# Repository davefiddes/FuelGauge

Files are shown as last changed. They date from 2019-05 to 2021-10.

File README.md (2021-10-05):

# Linear Fuel Gauge

This project allows an accurate linear fuel readout to be created for vehicles with unusually shaped fuel tanks and/or mismatched fuel senders.

## Why?

I built this for my Ultima GTR kit car which uses a conventional VDO fuel gauge and vertical float sender unit. The fuel tank on the car is a very unusual shape so it can get as much fuel as possible into a small space. This combination means that with a thirsty V8 the fuel quickly drops from 100% to 25% but takes a lot longer to go from 25% to empty. It's easy to run out of fuel!

To illustrate the scale of the problem here is a rendering of the fuel tank with 15 litres of fuel in a 34 litre tank:

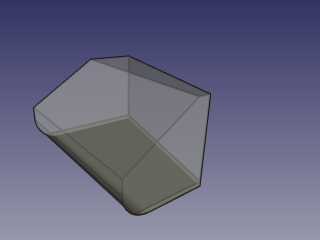
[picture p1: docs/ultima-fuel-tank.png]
Cutaway render of Ultima GTR fuel tank


Other Ultima owners have solved the problem by using their ECU or an intelligent dashboard. I have neither and wanted to preserve the original look of the Ultima branded instruments.

## How?

The Linear Fuel Gauge box sits between a standard resistance fuel sender and a hot-wire fuel gauge. The device:

* measures the resistance of the sender (0-100 ohms)
* maps that resistance to a linear fuel level value
* maps the fuel level to a particular gauge output value
* emulates the resistance value needed to achieve the required gauge output value

## Hardware

The gauge is built around a simple 8-pin PIC12F1840 micro-controller. The resistance of the sender is measured using a 10mA current source built from an LM317L regulator. The gauge output is achieved by feeding a PWM signal from the MCU into a high-current MOSFET driver (currents are typically around 100mA for 100%). A simple NPN-transistor driver is provided for low fuel indication. Configuration of the gauge is achieved with a 3-wire TTL serial connection to the MCU.

The project contains the full Kicad schematics and a PCB layout designed to fit in a small Hammond Manufacturing 1591ABK ABS plastic case.

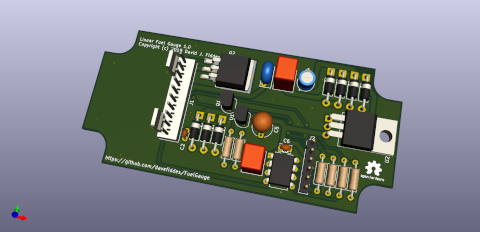
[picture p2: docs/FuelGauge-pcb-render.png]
Fuel Gauge PCB 3D render


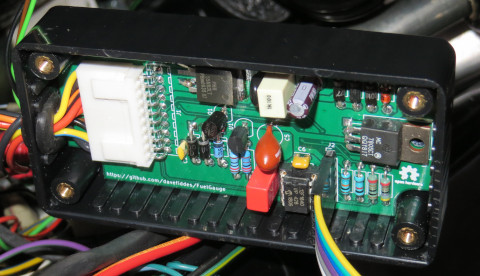
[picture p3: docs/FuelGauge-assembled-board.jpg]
Fuel Gauge assembled unit


Details:

* [Schematics](hardware/FuelGauge.pdf)
* [PCB Gerbers](hardware/gerbers/FuelGauge-1.0.zip)
* [BOM](docs/BOM.md)
* [Example Wiring Harness](wiring/wiring.pdf)

## Software



The gauge is implemented in C as a platform neutral core with a small hardware abstraction layer for the MCU. A full set of unit tests is provided for the core allowing easy testing and debugging to be carried out on a PC before building for the MCU. The MCU firmware is built using the Microchip MPLAB X IDE v5.15 and xc8 v2.05 compiler (Free Version).

 The gauge has two 9 bin maps that allow fine grained mapping of:

* the input resistance to a linear fuel level
* the linear fuel level to a PWM gauge output value

 The calibration of the two maps is achieved using a serial connection. The core implements a command processor allowing values in each of the maps to be modified and saved to EEPROM. During calibration the gauge output can be tested and the resistance of the fuel sender measured independently.

 The [Calibration And Programming Guide](docs/user-guide.md) details how to set up the fuel gauge which should mostly be a one-time exercise.

## License

 The device hardware and software is covered by the GNU General Public License v3.

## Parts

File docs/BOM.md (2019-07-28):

Fuel Gauge Bill of Materials
--------------------------------

Below is the Bill of Materials for the Fuel Gauge 1.0 board:

```
Ref(s)      Value                                   RS Components P/N
-------------------------------------------------------------------------------
C1,C2       1nF 100Vdc Multi-layer Ceramic 10%          699-5109
C3          1uF 100Vdc Polyester 10%                    126-2282
C4          22uF Aluminium Electrolytic 35Vdc           715-2729
C5          47uF 6.3V Radial Tantalum                   868-5690
C6          100nF 50Vdc Multi-layer Ceramic 10%         538-1310
D1,D2,D4,D6 1N4001                                      628-8931
D3          5V1 1W Zener Diode                          166-2747
D5          12V 1W Zener Diode                          687-5459
D7          22V 1.3W Zener Diode                        813-3915
J1          Molex KK 254 7395, 2.54mm Pitch, 10 Way     173-2994
            1 Row, Right Angle PCB Header
J2          6 Way 1 Row 2.54mm Pitch header
Q1          BC547 NPN Transistor TO-92                  671-1113
Q2          PHB55N03LT N-MOSFET transistor TO-263
R1          120R 1/4W 1% thin-film resistor
R2          2K2 1/4W 1% thin-film resistor
R3          1K 1/4W 1% thin-film resistor
R4          10R 1/4W 1% thin-film resistor
R5          4K7 1/4W 1% thin-film resistor
R6          10K 1/4W 1% thin-film resistor
RV1         Panasonic ERZV05D220 22V MOV                226-7817
U1          LM317L 100mA Linear regulator TO92          661-6796
U2          LM7805 700mA Linear Regulator TO220         785-6762
U3          Microchip PIC12F1840-I/P DIP-8              743-2697
```

Notes:
 * Q2 may be hard to find. Any power N-channel MOSFET in TO-263 package should suffice. I used a device recovered from a PC motherboard as that what I had available.

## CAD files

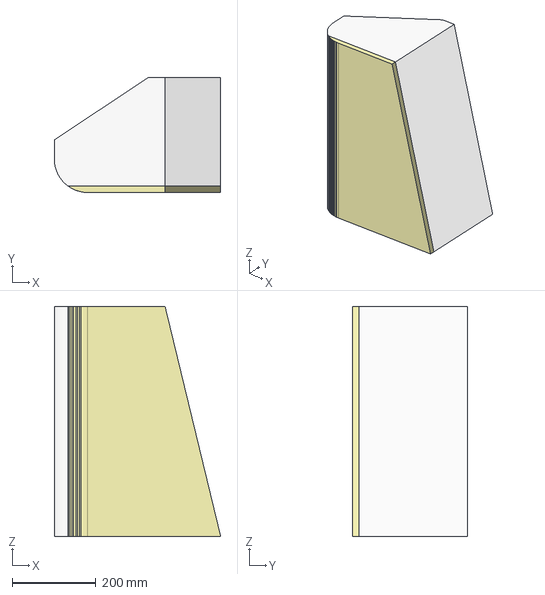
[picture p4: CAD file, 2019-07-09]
docs/ultima-fuel-tank.FCStd
398.0 x 275.0 x 550.0 mm
FuelTank
Fuel

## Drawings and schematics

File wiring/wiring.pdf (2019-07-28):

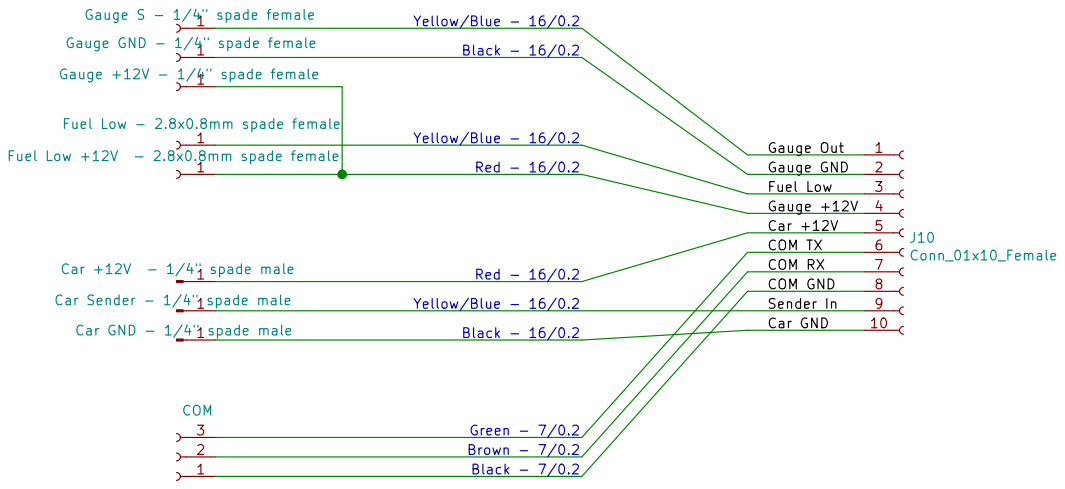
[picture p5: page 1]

Black - 16/0.2 Yellow/Blue - 16/0.2 Red - 16/0.2 Red - 16/0.2 Yellow/Blue - 16/0.2 Black - 16/0.2 Green - 7/0.2 Brown - 7/0.2 Black - 7/0.2

1 Gauge S - 1/4" spade female
1 Gauge GND - 1/4" spade female

1 Fuel Low - 2.8x0.8mm spade female

1 Fuel Low +12V - 2.8x0.8mm spade female

COM RX
Sender In COM GND

Car Sender - 1/4" spade male 1 Car GND - 1/4" spade male 1

File: wiring.sch Sheet: /
Id: 1/1 Title: Wiring Harness

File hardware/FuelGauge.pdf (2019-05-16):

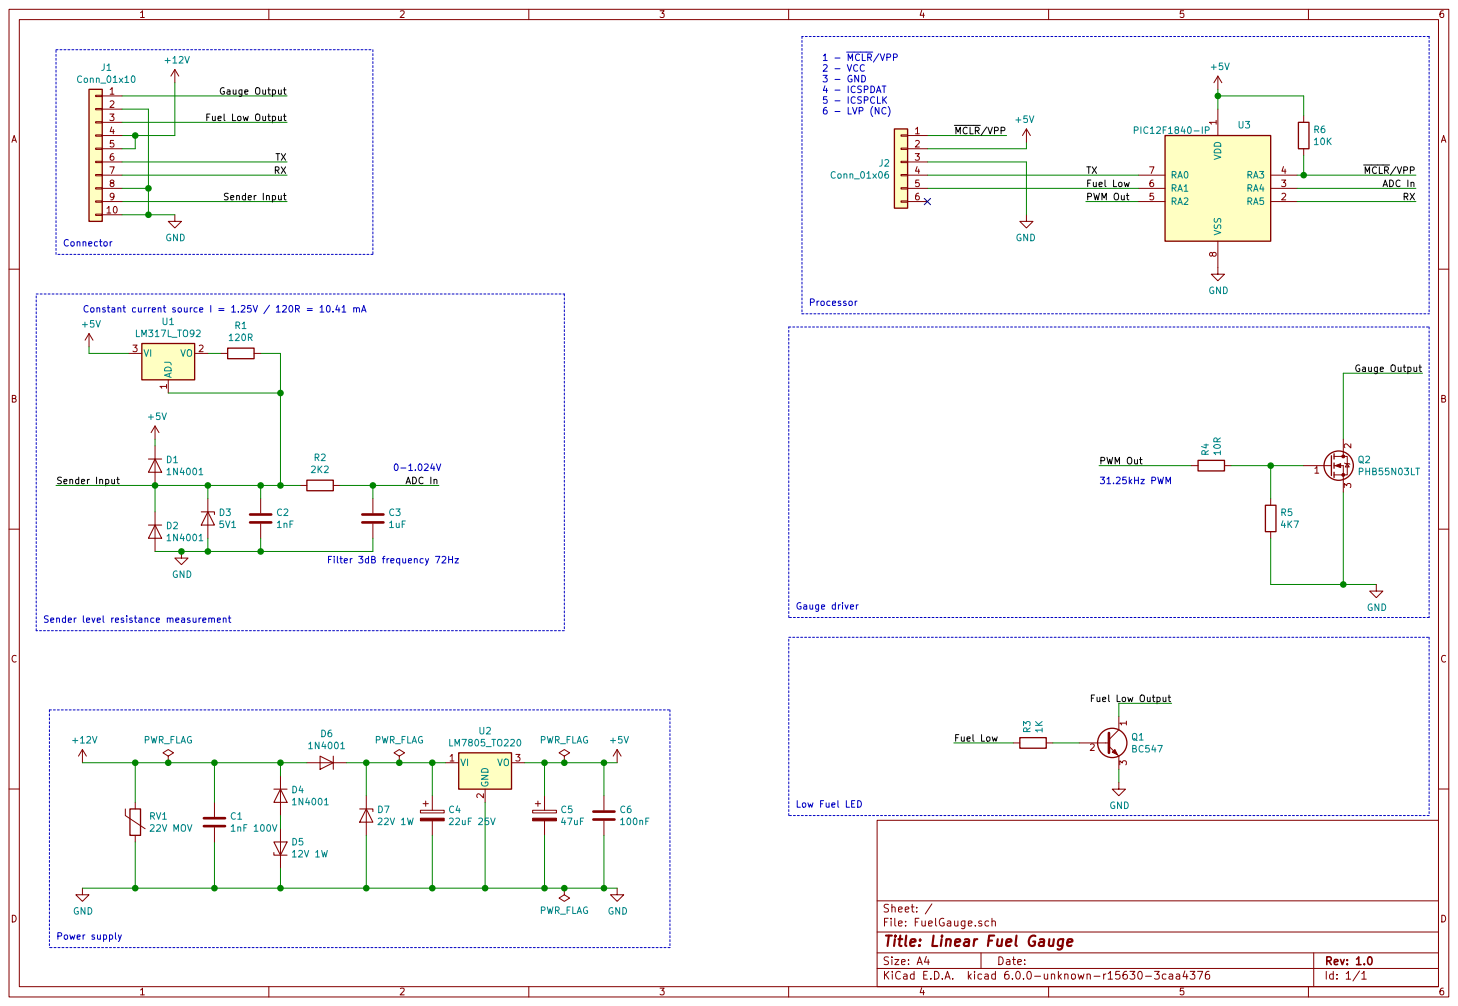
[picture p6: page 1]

+5V Constant current source I = 1.25V / 120R = 10.41 mA C2

File: FuelGauge.sch Sheet: / D6

Id: 1/1 Title: Linear Fuel Gauge

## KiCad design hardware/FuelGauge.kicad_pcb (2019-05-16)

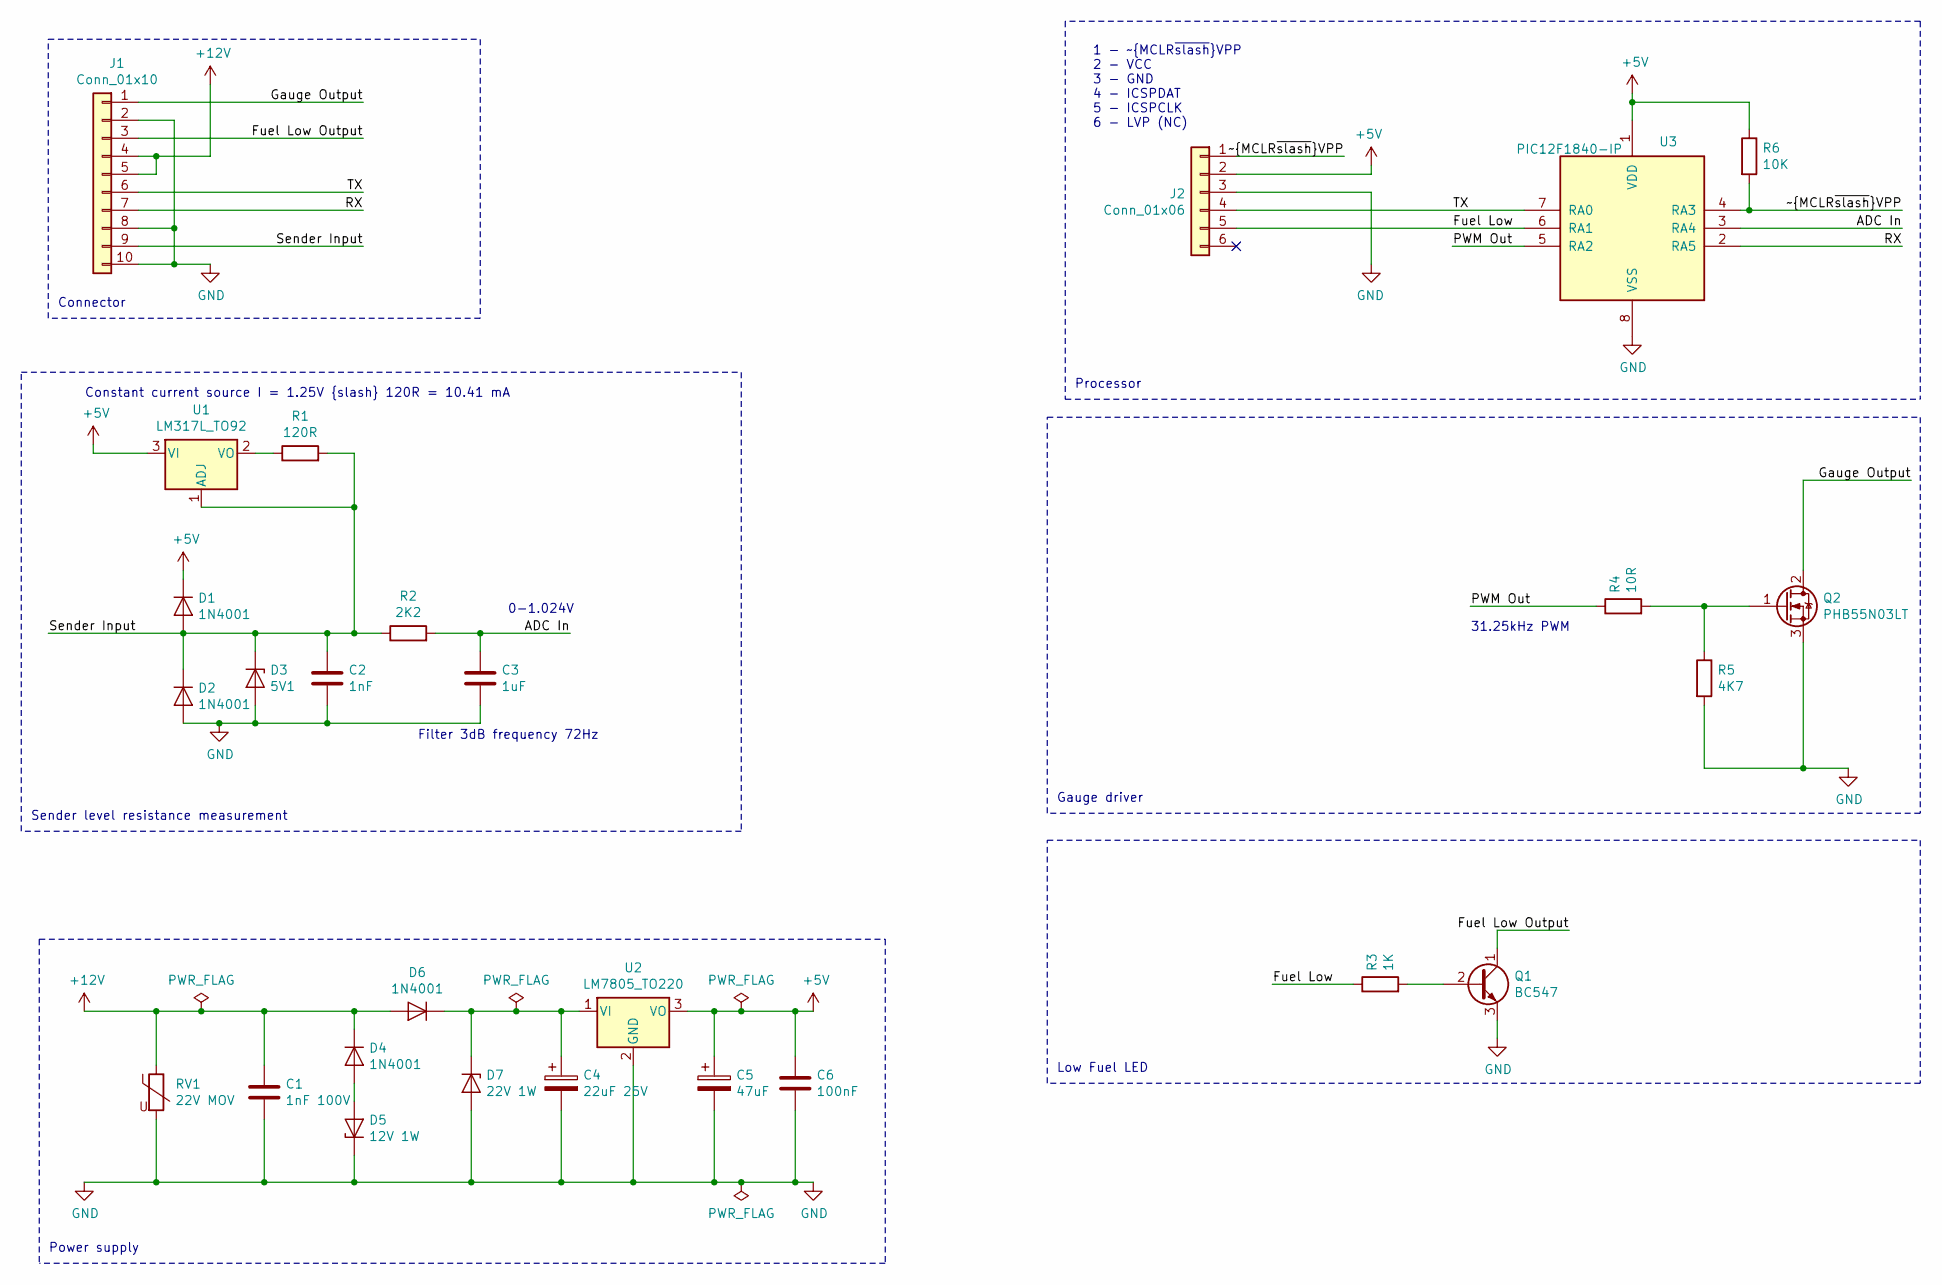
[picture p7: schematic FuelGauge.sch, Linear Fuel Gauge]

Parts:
C1: 1nF 100V; C_Rect_L7.0mm_W6.0mm_P5.00mm
C2: 1nF; C_Disc_D3.0mm_W1.6mm_P2.50mm
C3: 1uF; C_Rect_L7.0mm_W6.0mm_P5.00mm
C4: 22uF 25V; CP_Radial_D5.0mm_P2.00mm
C5: 47uF; CP_Radial_Tantal_D6.0mm_P5.00mm
C6: 100nF; C_Disc_D3.4mm_W2.1mm_P2.50mm
D1, D2, D4, D6: 1N4001; D_DO-41_SOD81_P10.16mm_Horizontal
D3: 5V1; D_DO-41_SOD81_P10.16mm_Horizontal
D5: 12V 1W; D_DO-41_SOD81_P10.16mm_Horizontal
D7: 22V 1W; D_DO-41_SOD81_P10.16mm_Horizontal
J1: Conn_01x10; Molex_KK-254_AE-6410-10A_1x10_P2.54mm_Vertical
J2: Conn_01x06; PinHeader_1x06_P2.54mm_Vertical
Q1: BC547; TO-92_Inline
Q2: PHB55N03LT; TO-263-3_TabPin2
R1: 120R; R_Axial_DIN0207_L6.3mm_D2.5mm_P10.16mm_Horizontal
R2: 2K2; R_Axial_DIN0207_L6.3mm_D2.5mm_P10.16mm_Horizontal
R3: 1K; R_Axial_DIN0207_L6.3mm_D2.5mm_P10.16mm_Horizontal
R4: 10R; R_Axial_DIN0207_L6.3mm_D2.5mm_P10.16mm_Horizontal
R5: 4K7; R_Axial_DIN0207_L6.3mm_D2.5mm_P10.16mm_Horizontal
R6: 10K; R_Axial_DIN0207_L6.3mm_D2.5mm_P10.16mm_Horizontal
RV1: 22V MOV; RV_Disc_D7mm_W3.4mm_P5mm
U1: LM317L_TO92; TO-92_Inline
U2: LM7805_TO220; TO-220-3_Horizontal_TabDown
U3: PIC12F1840-IP; DIP-8_W7.62mm

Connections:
+5V: C5.1, C6.1, D1.1 (K), J2.2, R6.1, U1.3 (VI), U2.3 (VO), U3.1 (VDD)
+12V: C1.1, D4.1 (K), D6.2 (A), J1.4, J1.5, RV1.1
/ADC In: C3.1, R2.2, U3.3 (RA4)
/Fuel Low: J2.5, R3.1, U3.6 (RA1)
/Fuel Low Output: J1.3, Q1.1 (C)
/Gauge Output: J1.1, Q2.2 (D)
/PWM Out: R4.1, U3.5 (RA2)
/RX: J1.7, U3.2 (RA5)
/Sender Input: C2.1, D1.2 (A), D2.1 (K), D3.1 (K), J1.9, R1.2, R2.1, U1.1 (ADJ)
/TX: J1.6, J2.4, U3.7 (RA0)
/~MCLR~/VPP: J2.1, R6.2, U3.4 (RA3)
GND: C1.2, C2.2, C3.2, C4.2, C5.2, C6.2, D2.2 (A), D3.2 (A), D5.1 (K), D7.2 (A), J1.2, J1.8, J1.10, J2.3, Q1.3 (E), Q2.3 (S), R5.2, RV1.2, U2.2 (GND), U3.8 (VSS)
unnamed: C4.1, D6.1 (K), D7.1 (K), U2.1 (VI)
unnamed: D4.2 (A), D5.2 (A)
unnamed: Q1.2 (B), R3.2
unnamed: Q2.1 (G), R4.2, R5.1
unnamed: R1.1, U1.2 (VO)

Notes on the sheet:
Constant current source I = 1.25V {slash} 120R = 10.41 mA
Filter 3dB frequency 72Hz
0-1.024V
31.25kHz PWM
Connector
Sender level resistance measurement
Processor
Gauge driver
Low Fuel LED
Power supply
1 - ~MCLR~{slash}VPP 2 - VCC 3 - GND 4 - ICSPDAT 5 - ICSPCLK 6 - LVP (NC)

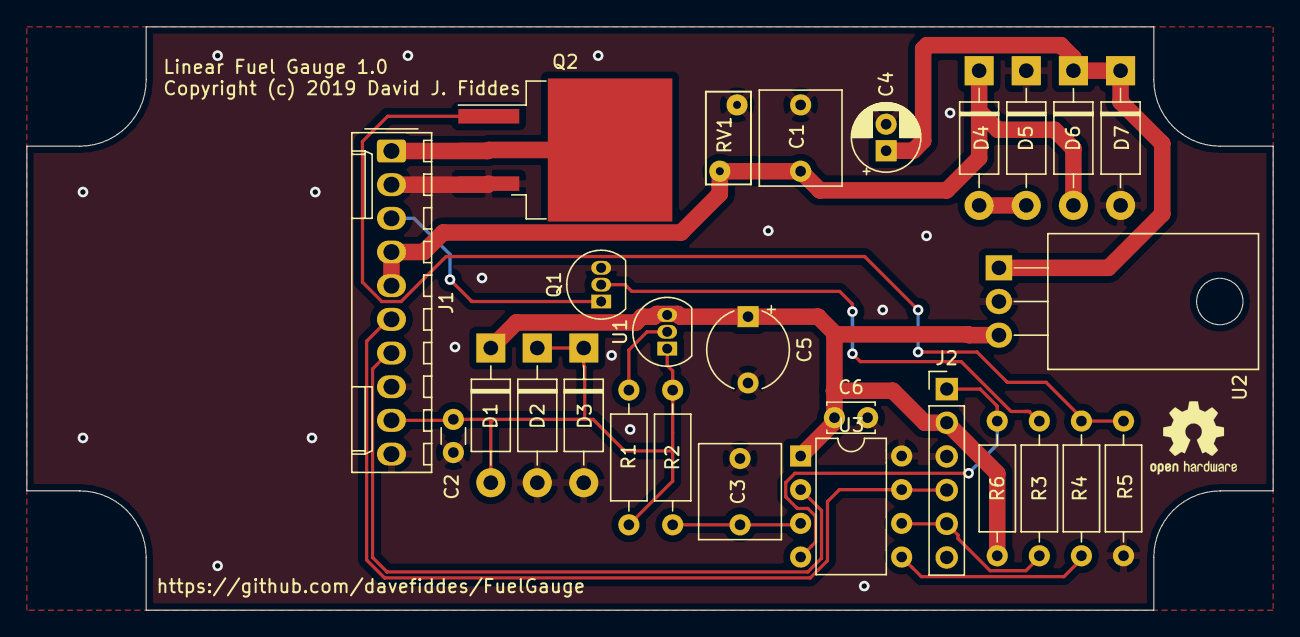
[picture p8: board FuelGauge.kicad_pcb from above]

Board: 2 copper layers, 94.0 x 44.0 mm, 28 parts (0 on the bottom side), 17 nets.

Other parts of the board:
Logo1: OSHW-Logo2_7.3x6mm_SilkScreen

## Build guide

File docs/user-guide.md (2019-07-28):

# Calibration And Programming Guide

## Connection

Connect to the Fuel Gauge using a 5V TTL capable USB serial device. Any common device should work whether based on FTDI, CP210x or CH340 chipsets. Use 9600 baud 8 bits and no-parity. TTL serial works surprisingly well even in a noisy vehicle environment and it saves the expense of an RS232 serial transceiver for a function that is rarely used.

## Usage

The fuel gauge offers a simple text based programming interface. The commands supported can be obtained by pressing `u` and then Enter:

```
FuelGauge Version a6408e

Press "u" for usage

u
Usage:
p               - Program mode
r               - Run mode
d               - Display current tank input value and output gauge value
g <Value>       - Output raw gauge value
t               - One shot test map the current tank input to the gauge output
i <Bin> <Value> - Set the input bin number to a specific linear tank value
o <Bin> <Value> - Set the output bin number to a specific value
m               - Display the input and output maps
s               - Save input and output maps to persistent storage
l               - Load input and output maps from persistent storage
f <Value>       - Set the low fuel limit
c               - Continuously output values as the gauge runs
u               - This usage information

OK
```

## Command Details

 * `p` - Changes from the normal running of the gauge to program mode. In this mode the sender input is no longer mapped to the output. This allows the gauge output to be manually altered. In particular this allows the output map to be created.

 * `r` - Restores the gauge to normal running operation

 * `d` - Display the raw values being read from the sender input, being output to the gauge and whether the device is in program or run mode. For example: `Tank: 0x1dbc Gauge: 0xffc0 Mode: Run`

 * `g` - Only available in program mode. This sets the gauge output to the specified 4-digit hex value. Useful for verifying what value is required for a given fuel gauge display.

 * `t` - Available in program mode this allows a one-shot test of mapping the current sender input through to the gauge output. This is handy for testing a map in response to a change in the sender input.

 * `i` - Used to configure a specific input map bin. The input map consists of 9 bins numbered 0 to 8. Each bin maps a given raw sender input value to a fixed _real_ fuel level value. For example bin 0 corresponds to empty, 4 to 50% full and 8 is 100% full.

 * `o` - Used to configure a specific output map bin. The output map consists of 9 bins numbered 0 to 8. In contrast to the input map the output map takes a _real_ fuel value and determines the raw gauge output value that is required.

 * `m` - Used to display the input and output maps and the configured low fuel light level

 * `s` - Save the current configuration to EEPROM. If this is not done it will be lost at the next power cycle.

 * `l` - Load the current configuration from EEPROM. This can be used if an error has been made during programming.

 * `f` - Set the fuel level which will cause the low fuel level warning lamp to illuminate. The value is in _real_ linear fuel level values. So 8000 means 50%, 2000 means 12.5% and so on.

 * `c` - Continuous mode will continuously log the sender input, actual fuel level and gauge output to the serial console several times a second. This allows rapid changes in the values to be quantified. This only available in run mode and when the sender input is not disconnected (a sender value of 0xffff).

 ## Calibration Procedure

 __**WARNING: Calibrating fuel gauges will likely involve moving measuring quantities of fuel around a vehicle. Please ensure appropriate ventilation, safety equipment and fire extinguishers. **__

 The first step is to calibrate the gauge output. Put the gauge into program mode and use the `g` command to set various values. The device is capable of generating a PWM output from 0% to 100% duty cycle. It is likely that the 0% gauge level will require a modest current on most hot-wire gauges. Note the gauge output values that achieve a given reading on the actual fuel gauge. Use these to program the output map. The map should work well for gauges which are divided into 1/8ths but may require a spreadsheet to figure out the values for a different graduations (e.g. 1/10ths).

 The next step is to determine the fuel tank calibration. To do this requires an empty fuel tank. Measure the empty fuel level using the `d` command and then store this in bin 0 of the input map using the `i` command. Add 1/8th of a tank of fuel using a calibrated measure and repeat until full.

 Finally set the low fuel warning level and save the map. Using a logging terminal like PuTTY and printing out a copy of the map with `m` will allow the maps to be restored in the case of an error.

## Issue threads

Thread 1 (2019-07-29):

It is difficult to remove the device from a vehicle

davefiddes, 2019-07-29:
I find it difficult to remove the device from a vehicle. It is possible to unplug the wiring harness from the PCB but only after unplugging from the 8 fiddling individual connections into my car's wiring loom. This makes it harder to remove the device for programming or testing as by necessity the wiring harness is short to allow it to be hidden under the dashboard.

A better choice might have been to use a DB-9 connector in place of the 10-pin 0.1" Molex header. This would allow external disconnection of the wiring harness from the device in a single operation. This would be similar to the DB-37 used by the MegaSquirt ECU.

It might be possible to wire a chassis mount DB-9 to the PCB but a PCB mount DB-9 connector would be neater.

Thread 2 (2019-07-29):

PCB footprint for U1 and Q1 is difficult to solder

davefiddes, 2019-07-29:
The choice of PCB footprint for the two TO-92 devices makes it difficult to solder manually. A more traditional footprint with offset middle pin and larger pads would be preferable as well as offering greater mechanical support for the devices.

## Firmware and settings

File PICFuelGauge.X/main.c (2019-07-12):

///////////////////////////////////////////////////////////////////////////////
//!
//! \file
//! \brief  Fuel Gauge main
//!
///////////////////////////////////////////////////////////////////////////////
// Copyright (c) 2019 David J. Fiddes
//
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
///////////////////////////////////////////////////////////////////////////////

#include "mcc_generated_files/mcc.h"
#include <command.h>
#include <ctype.h>
#include <hal.h>

//
//! Length of our input line buffer
//
#define BUFFERLEN 20

//
//! The number of loop iterations we need to flash at approx 1Hz
//
#define ERRORFLASHDURATION 1000

///////////////////////////////////////////////////////////////////////////////
//!
//! \brief  Device main loop
//!
///////////////////////////////////////////////////////////////////////////////
void main( void )
{
    // initialise the device
    SYSTEM_Initialize();

    // When using interrupts, you need to set the Global and Peripheral
    // Interrupt Enable bits Use the following macros to:

    // Enable the Global Interrupts
    // INTERRUPT_GlobalInterruptEnable();

    // Enable the Peripheral Interrupts
    // INTERRUPT_PeripheralInterruptEnable();

    // Disable the Global Interrupts
    // INTERRUPT_GlobalInterruptDisable();

    // Disable the Peripheral Interrupts
    // INTERRUPT_PeripheralInterruptDisable();

//
// Quote a version string to turn it into a C-string
//
#define VERSION_STR( x ) VERSION_STR1( x )
#define VERSION_STR1( x ) #x

    HAL_PrintText( "FuelGauge Version " VERSION_STR(
        GIT_VERSION ) "\r\n\r\nPress \"u\" for usage\r\n\r\n" );

    //
    // Check to see if we have experienced a watchdog reset.
    // Note: This needs the -mresetbits compiler option set otherwise this
    // information is clobbered by the normal start up code
    //
    if ( __timeout == 0 )
    {
        HAL_PrintText( "Watchdog timeout\r\n\r\n" );
    }

    //
    // Start the PWM output
    //
    TMR2_StartTimer();

    InitialiseGauge();

    char        rxData;
    char        lineBuffer[ BUFFERLEN ];
    const char* lineBufferBegin = &lineBuffer[ 0 ];
    const char* lineBufferEnd = lineBufferBegin + BUFFERLEN;
    char*       bufferPos = (char*)lineBufferBegin;
    int         errorCount = 0;

    *bufferPos = '\0';

    while ( 1 )
    {
        //
        // Check to see if we have a character waiting
        //
        if ( EUSART_is_rx_ready() )
        {
            rxData = EUSART_Read();

            if ( rxData == '\r' )
            {
                //
                // Echo the CR before doing any work
                //
                HAL_PrintNewline();

                *bufferPos = '\0';

                //
                // Process our line buffer as a new command
                //
                if ( ProcessCommand( lineBuffer ) )
                {
                    HAL_PrintText( "OK" );
                    HAL_PrintNewline();
                }
                else
                {
                    HAL_PrintText( "Command Error" );
                    HAL_PrintNewline();
                }
                bufferPos = (char*)lineBufferBegin;
                *bufferPos = '\0';
            }
            else if ( isprint( rxData ) )
            {
                //
                // Local echo
                //
                if ( EUSART_is_tx_ready() )
                {
                    EUSART_Write( rxData );
                }

                //
                // Store the character in our line buffer and check for length
                //
                *bufferPos = rxData;
                bufferPos++;
                if ( bufferPos == lineBufferEnd )
                {
                    HAL_PrintNewline();
                    HAL_PrintText( "Line too long" );
                    HAL_PrintNewline();
                    bufferPos = (char*)lineBufferBegin;
                    *bufferPos = '\0';
                }
            }
        }

        //
        // Run the gauge main loop
        //
        if ( !RunGauge() )
        {
            //
            // If we don't already have an error flash in progress start a
            // new one
            //
            if ( errorCount == 0 )
            {
                //
                // The error flash will have a 50% duty cycle so double the
                // interations
                //
                errorCount = ERRORFLASHDURATION * 2;
                lowFuel_SetHigh();
            }
        }

        //
        // If we have an outstanding error take care of flashing the low fuel
        // LED
        //
        if ( errorCount > 0 )
        {
            if ( errorCount == ERRORFLASHDURATION )
            {
                lowFuel_SetLow();
            }
            errorCount--;

            //
            // Wait for 1ms which should be enough to keep the main loop
            // responsive but not require huge numbers of iterations to build
            // longer delays for the error flash
            //
            __delay_ms( 1 );
        }

        //
        // Strobe the watchdog every time round the main loop so we don't reboot
        //
        CLRWDT();
    }
}

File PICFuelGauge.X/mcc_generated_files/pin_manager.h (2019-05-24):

/**
  @Generated Pin Manager Header File

  @Company:
    Microchip Technology Inc.

  @File Name:
    pin_manager.h

  @Summary:
    This is the Pin Manager file generated using PIC10 / PIC12 / PIC16 / PIC18 MCUs

  @Description
    This header file provides APIs for driver for .
    Generation Information :
        Product Revision  :  PIC10 / PIC12 / PIC16 / PIC18 MCUs - 1.76
        Device            :  PIC12F1840
        Driver Version    :  2.11
    The generated drivers are tested against the following:
        Compiler          :  XC8 2.00
        MPLAB 	          :  MPLAB X 5.10	
*/

/*
    (c) 2018 Microchip Technology Inc. and its subsidiaries. 
    
    Subject to your compliance with these terms, you may use Microchip software and any 
    derivatives exclusively with Microchip products. It is your responsibility to comply with third party 
    license terms applicable to your use of third party software (including open source software) that 
    may accompany Microchip software.
    
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
    IN NO EVENT WILL MICROCHIP BE LIABLE FOR ANY INDIRECT, SPECIAL, PUNITIVE, 
    INCIDENTAL OR CONSEQUENTIAL LOSS, DAMAGE, COST OR EXPENSE OF ANY KIND 
    WHATSOEVER RELATED TO THE SOFTWARE, HOWEVER CAUSED, EVEN IF MICROCHIP 
    HAS BEEN ADVISED OF THE POSSIBILITY OR THE DAMAGES ARE FORESEEABLE. TO 
    THE FULLEST EXTENT ALLOWED BY LAW, MICROCHIP'S TOTAL LIABILITY ON ALL 
    CLAIMS IN ANY WAY RELATED TO THIS SOFTWARE WILL NOT EXCEED THE AMOUNT 
    OF FEES, IF ANY, THAT YOU HAVE PAID DIRECTLY TO MICROCHIP FOR THIS 
    SOFTWARE.
*/

#ifndef PIN_MANAGER_H
#define PIN_MANAGER_H

/**
  Section: Included Files
*/

#include <xc.h>

#define INPUT   1
#define OUTPUT  0

#define HIGH    1
#define LOW     0

#define ANALOG      1
#define DIGITAL     0

#define PULL_UP_ENABLED      1
#define PULL_UP_DISABLED     0

// get/set RA0 procedures
#define RA0_SetHigh()            do { LATAbits.LATA0 = 1; } while(0)
#define RA0_SetLow()             do { LATAbits.LATA0 = 0; } while(0)
#define RA0_Toggle()             do { LATAbits.LATA0 = ~LATAbits.LATA0; } while(0)
#define RA0_GetValue()              PORTAbits.RA0
#define RA0_SetDigitalInput()    do { TRISAbits.TRISA0 = 1; } while(0)
#define RA0_SetDigitalOutput()   do { TRISAbits.TRISA0 = 0; } while(0)
#define RA0_SetPullup()             do { WPUAbits.WPUA0 = 1; } while(0)
#define RA0_ResetPullup()           do { WPUAbits.WPUA0 = 0; } while(0)
#define RA0_SetAnalogMode()         do { ANSELAbits.ANSA0 = 1; } while(0)
#define RA0_SetDigitalMode()        do { ANSELAbits.ANSA0 = 0; } while(0)

// get/set lowFuel aliases
#define lowFuel_TRIS                 TRISAbits.TRISA1
#define lowFuel_LAT                  LATAbits.LATA1
#define lowFuel_PORT                 PORTAbits.RA1
#define lowFuel_WPU                  WPUAbits.WPUA1
#define lowFuel_ANS                  ANSELAbits.ANSA1
#define lowFuel_SetHigh()            do { LATAbits.LATA1 = 1; } while(0)
#define lowFuel_SetLow()             do { LATAbits.LATA1 = 0; } while(0)
#define lowFuel_Toggle()             do { LATAbits.LATA1 = ~LATAbits.LATA1; } while(0)
#define lowFuel_GetValue()           PORTAbits.RA1
#define lowFuel_SetDigitalInput()    do { TRISAbits.TRISA1 = 1; } while(0)
#define lowFuel_SetDigitalOutput()   do { TRISAbits.TRISA1 = 0; } while(0)
#define lowFuel_SetPullup()          do { WPUAbits.WPUA1 = 1; } while(0)
#define lowFuel_ResetPullup()        do { WPUAbits.WPUA1 = 0; } while(0)
#define lowFuel_SetAnalogMode()      do { ANSELAbits.ANSA1 = 1; } while(0)
#define lowFuel_SetDigitalMode()     do { ANSELAbits.ANSA1 = 0; } while(0)

// get/set RA2 procedures
#define RA2_SetHigh()            do { LATAbits.LATA2 = 1; } while(0)
#define RA2_SetLow()             do { LATAbits.LATA2 = 0; } while(0)
#define RA2_Toggle()             do { LATAbits.LATA2 = ~LATAbits.LATA2; } while(0)
#define RA2_GetValue()              PORTAbits.RA2
#define RA2_SetDigitalInput()    do { TRISAbits.TRISA2 = 1; } while(0)
#define RA2_SetDigitalOutput()   do { TRISAbits.TRISA2 = 0; } while(0)
#define RA2_SetPullup()             do { WPUAbits.WPUA2 = 1; } while(0)
#define RA2_ResetPullup()           do { WPUAbits.WPUA2 = 0; } while(0)
#define RA2_SetAnalogMode()         do { ANSELAbits.ANSA2 = 1; } while(0)
#define RA2_SetDigitalMode()        do { ANSELAbits.ANSA2 = 0; } while(0)

// get/set tank aliases
#define tank_TRIS                 TRISAbits.TRISA4
#define tank_LAT                  LATAbits.LATA4
#define tank_PORT                 PORTAbits.RA4
#define tank_WPU                  WPUAbits.WPUA4
#define tank_ANS                  ANSELAbits.ANSA4
#define tank_SetHigh()            do { LATAbits.LATA4 = 1; } while(0)
#define tank_SetLow()             do { LATAbits.LATA4 = 0; } while(0)
#define tank_Toggle()             do { LATAbits.LATA4 = ~LATAbits.LATA4; } while(0)
#define tank_GetValue()           PORTAbits.RA4
#define tank_SetDigitalInput()    do { TRISAbits.TRISA4 = 1; } while(0)
#define tank_SetDigitalOutput()   do { TRISAbits.TRISA4 = 0; } while(0)
#define tank_SetPullup()          do { WPUAbits.WPUA4 = 1; } while(0)
#define tank_ResetPullup()        do { WPUAbits.WPUA4 = 0; } while(0)
#define tank_SetAnalogMode()      do { ANSELAbits.ANSA4 = 1; } while(0)
#define tank_SetDigitalMode()     do { ANSELAbits.ANSA4 = 0; } while(0)

// get/set RA5 procedures
#define RA5_SetHigh()            do { LATAbits.LATA5 = 1; } while(0)
#define RA5_SetLow()             do { LATAbits.LATA5 = 0; } while(0)
#define RA5_Toggle()             do { LATAbits.LATA5 = ~LATAbits.LATA5; } while(0)
#define RA5_GetValue()              PORTAbits.RA5
#define RA5_SetDigitalInput()    do { TRISAbits.TRISA5 = 1; } while(0)
#define RA5_SetDigitalOutput()   do { TRISAbits.TRISA5 = 0; } while(0)
#define RA5_SetPullup()             do { WPUAbits.WPUA5 = 1; } while(0)
#define RA5_ResetPullup()           do { WPUAbits.WPUA5 = 0; } while(0)

/**
   @Param
    none
   @Returns
    none
   @Description
    GPIO and peripheral I/O initialization
   @Example
    PIN_MANAGER_Initialize();
 */
void PIN_MANAGER_Initialize (void);

/**
 * @Param
    none
 * @Returns
    none
 * @Description
    Interrupt on Change Handling routine
 * @Example
    PIN_MANAGER_IOC();
 */
void PIN_MANAGER_IOC(void);



#endif // PIN_MANAGER_H
/**
 End of File
*/

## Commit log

2019-05-03 Initial command processor, bare bones HAL and tests
    This is an initial fuel gauge command processor. It is capable of
    reading tank input values, setting gauge output values and switching
    between run and program modes.
    A bare bones HAL is defined and test implementation provided to
    verify correct operation.
    Tests:
    - Run unit tests
    [CommandTest.cpp]
2019-05-04 Implement map modification
    This adds support for editing individual values stored in bins of the
    input ("i") or output ("o") maps. The parsing of values is very
    tolerant as anything that can be contained in a 16-bit value is valid.
    The bin number can be between 0 and 8.
    Tests updated to verify new functionality and a trivial error in the
    size used by the MapLoadAndSave has been fixed.
    Tests
    - Run unit tests under valgrind
    [CommandTest.cpp]
2019-05-04 Initial MPLAB X project for PIC Fuel Gauge
    This is an initial MPLABX project targeting a PIC12F1840
    microcontroller. This has the following pinout:
    Pin 1 - Vdd
    Pin 2 - UART RX
    Pin 3 - Analog In (0-5V)
    Pin 4 - MCLR Reset
    Pin 5 - PWM Output
    Pin 6 - N/C
    Pin 7 - UART TX
    Pin 8 - VSS
    The main samples the analog in and outputs the current value on
    the serial port before programming the PWM output.
    The project uses MPLAB Code Configurator to define access to all
    peripherals.
    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
2019-05-05 Remove printf dependency
    Remove the printf dependency by adding a simpler print text and
    newline HAL. Two simple routines are added to format uint16_t
    values and bin numbers. The buffers for these are added on the
    stack which may require changing to be static depending on how
    XC8 reacts.
    The newlines in the test case have been removed as these are
    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
2019-05-05 Refactor to remove scanf from command processing
    This change removes the use of scanf from command processing
    and replaces with a simple value and bin parser. This removes any dependency on stdio.h which should reduce the code and
    data usage when built for the PIC.
    An additional success test case has been added for the g
    command.
    - Run all unit tests
    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
    [CommandTest.cpp]
2019-05-06 Fix a problem where we output to the gauge when not running
    This addresses a problem where the gauge output would change
    when RunGauge() was called from the main loop but the gauge
    was not in Run mode.
    - Run updated unit tests
    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
    [CommandTest.cpp]
2019-05-06 Optimise and rebuild PIC code
    This change regenerates all of the PIC peripheral code to use the
    latest libraries. This does not appear to affect any of the functions
    or configurations used.
    Compiler optimisation is turned up to -O2.
    - Project rebuilt and loaded onto device.
    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
2019-05-06 Initial PIC Fuel Guage integration
    This integrates the library with the core application logic with a
    simple HAL for a PIC12F1840 MCU. The main loop uses polling to
    sample the serial port for key presses and build up a command
    buffer which is then sent to the application logic when carriage-
    return is pressed.
    - Use all commands and verify basic operation
    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
2019-05-06 Refactor Map Load and Save to remove failure path
    The ability to failure when saving or loading maps just seems to add
    complication. The EEPROM operations don't seem to be easy to
    detect failure. This change removes this from the HAL as a
    simplification.
    - Save and load both maps on the target device
    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
    [CommandTest.cpp, pichal.c]
2019-05-06 Update the display to include the current mode
    It wasn't possible to determine the mode the guage was running in.
    This adds that to the display "d" command.
    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
2019-05-06 Display usage on start up and on request
    To save from future confusion the device now displays usage
    information on start up and on request with the "u" command.
    - Verify output on startup and on issuing the "u" command
    - Run updated (noddy) unit test
    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
2019-05-08 Basic schematic design for a PIC12F1840 based fuel gauge
    This is an outline design for a PIC based fuel gauge. It uses a simple current source (LM317 or discrete) to measure the
    resistance of a fuel sender (0-100R). The PWM output of the MCU
    is output through a MOSFET driver and power MOSFET from
    https://tahmidmc.blogspot.com/2012/12/low-side-mosfet-drive-circuits-and_23.html
    The changeset only contains a schematic and is intended for
    breadboarding at this point.
    [FuelGauge.kicad_pcb, FuelGauge.sch]
2019-05-09 Change the ADC reference to be 1.024V
    This changes the ADC voltage reference to use the FVR rather
    than the VDD supply rail. Using this voltage reference for the ADC
    allows it to produce accurate readings when hooked up to the
    resistance sensing hardware rather than a 100k ohm pot
    connected between the supply rails.
    - Check with 0R, 33R, 66R and 100R that the output PWM values
    with a linear 1:1 mapping are correct on a scope.
    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
2019-05-10 Average tank input values
    To increase the accuracy a number of readings are taken from the
    ADC and then averaged.
    - Run on a breadboarded PIC and check that the variance
    reported using the "d" command is less unstable. It is still noisy
    but this appears to be just breadboard/ADC noise.
    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
    [pichal.c]
2019-05-11 Feature complete HW design with hack PCB layout
    This completes the HW after testing on a breadboard. Both the
    sender input and gauge output have been tested.
    A fuel low output has been hacked together though this has no
    software currently and may be replaced with a 12V indicator.
    The PCB layout is functional and passes DRC but is pretty awful
    otherwise.
    - Run clean run of ERC on the schematics and DRC on the PCB.
    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
    [FuelGauge.kicad_pcb, FuelGauge.sch]
2019-05-13 Reroute to a smaller 49x81mm board
    This re-lays out the board to a much smaller form factor with more intelligent routing. The track size for power nets is reduced
    to 1.2mm which should be good for 2.7A max current. A number
    of ground plane vias have been thrown in with little thought to
    achieve better coverage.
    [FuelGauge.kicad_pcb]
2019-05-16 Version 1.0 hardware
    This change contains what is hoped to be 1.0 hardware. It removes the complex MOSFET driver for a simple direct drive
    from the MCU. The LED has been removed as this appears to
    provide little value as the VDO test guage uses 65% to 98% duty
    cycle to cover 0% to 100% which is virtually imperceptible.
    A simple transistor driver for a low fuel warning LED or lamp has
    been included. This should work with a 12V LED indicator lamp.
    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
    [FuelGauge.kicad_pcb, FuelGauge.sch]
2019-05-16 Manufacturing files submitted for 1.0 hardware
    This updates the PDF with the final schematic. It also updates the
    PCB to include the back solder mask which was missing. The
    gerbers areplotted from this, zipped and included in the source tree.
    The Kicad cache files which don't need to be version tracked are
    excluded from git.
    - Submit to JLCPCB for manufacture and check with their online
    Gerber viewer that the PCB design matches Kicad.
    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
    [FuelGauge-B_Cu.gbr, FuelGauge-B_Mask.gbr, FuelGauge-Edge_Cuts.gbr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]
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2019-05-18 Provide a basic set of project documentation
    This includes a bit of basic project oducmentation that covers the
    motivation, how the device works and little bit of information on the
    hardware and software. Much still left to write.
    A FreeCAD model of the Ultima fuel tank is included along with a
    render. A render of the PCB from Kicad is also included.
    - Proof read in Markdown view in Firefox
    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
    [ultima-fuel-tank.FCStd]
2019-05-24 Implement a Low Fuel Warning Light
    This change implements a low fuel warning light. The light is
    attached to pin6 of the MCU and is activated by pulling this GPIO
    pin low.
    A low fuel level setting is maintained in EEPROM alongside the
    input and output maps. It is configured using the new "f"
    command which is similar to the existing "g" gauge output
    The fuel level is checked each time the gauge main loop is run.
    The actual linear fuel level is the valu that is checked.
    A new set of unit tests are included which fully excercise the
    loading and storing of the fule level setting.
    Fix a number of misspellings of gauge in code comments.
    - Run the unit tests
    - Test on real HW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
    [CommandTest.cpp, pichal.c, pin_manager.h]
2019-05-28 Add a mode for continously logging gauge values as it runs
    This adds a mode which enables the gauge to continously log
    tank input, actual fuel level and gauge output values as the
    gauge runs. This is the same output as achieved using the "t"
    one-shot command. The new mode is enabled by the "c"
    continous mode command which toggles the output on or
    off.
    The duplicate comment documenting the command usage
    has been removed as it was already starting to drift from the
    usage command output.
    Usage information is shuffled so that the new commands are
    before the "u" usage command.
    - Enasure that on gauge start up no additional output is
    present
    - Enable contin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
    [CommandTest.cpp]
2019-05-28 Generate a version number from the current git commit
    This generates a version number for the firmware from the
    current git commit. Based on a recipe from:
    https://www.microchip.com/forums/m995841.aspx
    The usage print out on start-up has been removed which
    speeds start up significantly.
    - Build version and verify output version matches running
    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
2019-05-28 Indicate an error with the tank input being out of range
    This checks the tank input ADC to see if it is going full scale.
    This indicates that there is an error with the sender
    resistance sensing. The error is indicated to the user by
    flashing the low fuel indicator.
    Slightly odd side-effect is that in continuous mode the sensor
    logging output stops while there is an error. Outputting text
    at the same time as flashing the LEDs is difficult due to dumb
    loop used.
    - Run updated unit tests which check the return result of
    RunGauge()
    - Run the gauge on the target HW and force ADC errors
    using a 0-5V pot (expected input 0-1.024V)
    - Run in normal and ocntinuous logging modes and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
    [CommandTest.cpp, main.c, pichal.c]
2019-05-28 Fix TankInputValidation unit test error
    Having tried to log the input error in continuous mode this
    broke the flashing (by delaying for too long). The unit test was not updated to remove the expectation of the new error.
    This change fixes that.
    - Run updated unit tests successfully.
    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
    [CommandTest.cpp]
2019-05-29 Enable the system watchdog
    This enables the system watchdog on the PIC MCU. The default 2 second timeout is used as this should be long
    enough to cover and eventuality in gauge operation.
    The watchdog is strobed each time around the main loop
    which should be at most every 1ms. The MCC code generator
    inserts other watchdog strobes in the flash programming
    (unused) and UART reading.
    Should the watchdog trigger a message is printed to the
    console. It doesn't seem serious enough to warrant strobing
    the low fuel LED.
    According to the XC8 compiler manual the -mresetbits
    option is required to detect the watchdog timeout on start
    up. Testing reveals no difference in operation. The compiler
    option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
    [main.c]
2019-05-30 Fix a sensor error not being reported on startup
    This fixes an issue found where the board starts up without a
    sensor connected but the low fuel LED would not flash to
    indicate the error condition. Upon inspection it appears that
    the errorCount is not being initialised. This causes the
    errorCode value to contain random values which can take a
    long time in the error condition before it starts flashing.
    - Power the unit on with no sender unit conected and verify
    that the low fuel LED flashses at 1Hz as expected
    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
    [main.c]
2019-07-07 Replace the over-optimised implementation of MapValue()
    This replaces the over-optimised implementation of
    MapValue() which makes a static assumption that the top 3
    bits can be used to identify the output map bin by one which
    uses an explicit input map. This is much more accurate.
    Update all the tests across the system to remove the fudging
    required because the top value cannot fit 0x10000 in a
    uint16_t.
    - Run updated unit tests having checked each value change
    manually.
    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
    [CommandTest.cpp]
2019-07-08 Change input mapping direction to be more logical
    This change uses the new mapping function to allow the tank
    input values to be mapped to the linear actual values
    accurately and to use the full scale.
    The change removes the original MapValue function and
    replaces it with the new input/output map function. This
    requires extensive refactoring of the original MapperTest
    unit and renaming in InputMapperTest. The logic and values
    in each test is unchanged.
    The change in mapping semantics results in re-applying a
    fudge to the gauge mapping tests due to the loss of precision
    in the upper bin e000-ffff.
    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
    [CommandTest.cpp]
2019-07-08 Print the full map for input and output
    Now that a more flexible scheme has been adopted for
    mapping between the tank input, actual fuel level and gauge
    output display the full details of the input and output maps.
    Update the expected text output for the tests.
    Test:
    - Run updated tests
    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
2019-07-09 Update fuel tank model with measured tank dimensions
    This updates the Ultima fuel tank model to match the dimensions measured on the car. Fuel level set for 5 litres visible.
    The rendering used in the documentation has been updated
    to match the new model.
    [ultima-fuel-tank.FCStd]
2019-07-09 Update fuel tank model POV
    Actually save the FreeCAD model of the fuel tank with the POV
    used in the documentation.
    [ultima-fuel-tank.FCStd]
2019-07-10 Fix problems with decreasing maps at the extents
    This fixes a bug observed during real tank calibration where
    when the value read from the tank was the same or exceeded
    the 100% full value it was reporting an actual tank level of
    0x0000 rather than 0xffff.
    The problem was due to the bin scanning identification not
    having the correct comparison operator for the numbers in
    the map.
    - Create a new map with the actual calibration values and
    create tests representing the problem observed. Run the
    new tests.
    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
2019-07-11 Fix accidental disabling of low fuel warning lamp
    Revert the accidental commenting out of the low fuel warning lamp code introduced in 7e72d4.
    - None. To be tested in vehicle.
    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
    [pichal.c]
2019-07-12 Fix Windows build using MPLABX
    This fixes the Windows build of the project using MPLABX v5.15 by:
    - Adding proper stringification of the GIT_VERSION which
    seems to be required with the Windows version of the xc8
    compiler
    - Remove generated files from the MPLABX/NetBeans
    project. These are quite different between the Windows
    and Linux builds and are auto generated each time the
    project is opened.
    - Build on Linux and Windows with MPLABX 5.15 and
    xc8 2.05
    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
    [main.c]
2019-07-12 Properly escape the git version string
    This fixes an error in the stringify macro used to include the
    git version that resulted in the string GIT_VERSION being
    displayed rather than the actual hash.
    The quoting in the define passed to the compiler has been
    removed as this caused differences between the Linux and
    Windows builds.
    [main.c]
2019-07-28 Add a wiring harness diagram
    This add a wiring harness diagram showing how the board may
    be connected to a vehicle.
    [wiring.sch]
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2021-10-05 Switch from Travis-CI to Github Actions
    Switch away from using Travis-CI to Github Actions to
    match my other projects.
    Tidy the README.md with lint changes and a new path for
    the CI success/fail badge.
    - Verify build post-push.
    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

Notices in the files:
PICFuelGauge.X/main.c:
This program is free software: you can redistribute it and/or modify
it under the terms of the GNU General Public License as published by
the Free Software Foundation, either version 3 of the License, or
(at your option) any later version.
